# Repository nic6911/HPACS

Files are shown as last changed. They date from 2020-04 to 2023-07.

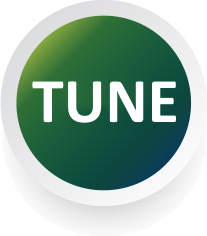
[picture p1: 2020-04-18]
Software/HMI/tune2.png

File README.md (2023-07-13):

# HPACS
Hot Plate Automatic Control System
Videos: https://youtu.be/TlVIJFjHHOQ and https://youtu.be/JZ1UPQ5lsyg

For a bit more details look here: https://www.instructables.com/Hot-Plate-Automatic-Control-System-HPACS/

If you like then please

"Buy Me A Coffee" (https://bmc.link/nic6911w)

## Purpose
This project aims at providing a simple intuitive way of understanding how to do Automatic PID tuning using a heater. What I have made is based on the Åström–Hägglund method for deriving parameters using bang-bang control to reveal system characteristics and subsequenctly chose parameters based on this knowledge. There is nothing secret to it and info can be found here: https://en.wikipedia.org/wiki/PID_controller#Loop_tuning
And for chosing parameters you can read a bit here: https://en.wikipedia.org/wiki/Ziegler%E2%80%93Nichols_method

To make it nice a Nextion 3.2" HMI interface is added for user input and displaying different variables real-time. BUT I also made a Serial terminal version of the library which makes the project way cheaper !

The real background story is that partly I promised my dad to make a temperature control for melting bees wax, partly I wanted to refresh my basic control theory and finally I wanted to look into auto tuning of PID controllers. On the side I also managed to use it for Sous Vide making nice steaks and Bearnaise sauce as part of the testing !

## Arduino based
The code is implemented on an Arduino Mega and uses two of the 16-bit timers for "PWM" and control loop. Furthermore, a Nextion 3.2" basic HMI panel is used on the HMI version of the code. I am not a software engineer so my coding may not be optimal or directly intuitive to others...

### Dependencies
I use a couple of libraries in the code: "DallasTemperature", "EEPROMex", "ITEADLIB_Arduino_Nextion-master" and the more commonly known "OneWire".

## Hardware/BOM
I use:
* A cheap WASCO Hot Plate 
* A cheap SS-relay
* A Dallas onewire temperature sensor 
* An Arduino Mega 
* (Optional) A Nextion 3.2" HMI interface/display

This work is licensed under a
[Creative Commons Attribution-ShareAlike 4.0 International License][cc-by-sa].

[][cc-by-sa]

[cc-by-sa]: http://creativecommons.org/licenses/by-sa/4.0/
[cc-by-sa-image]: https://licensebuttons.net/l/by-sa/4.0/88x31.png
[cc-by-sa-shield]: https://img.shields.io/badge/License-CC%20BY--SA%204.0-lightgrey.svg

Find more of my work here:  
https://youtube.com/user/wan46696  
https://www.instructables.com/member/nicengineering/  
        
License note: However, I have found the buttons for the HMI here: https://www.uihere.com/free-graphics/off-and-on-button-set-ai-eps-file-131170
Where it says "For Personal Use" under licensing - I.e. no commercialization of HPACS unless you change those buttons ;)
Also the disk icon and the hot surface warning I found somewhere at some point - but I can't seem to find them again...

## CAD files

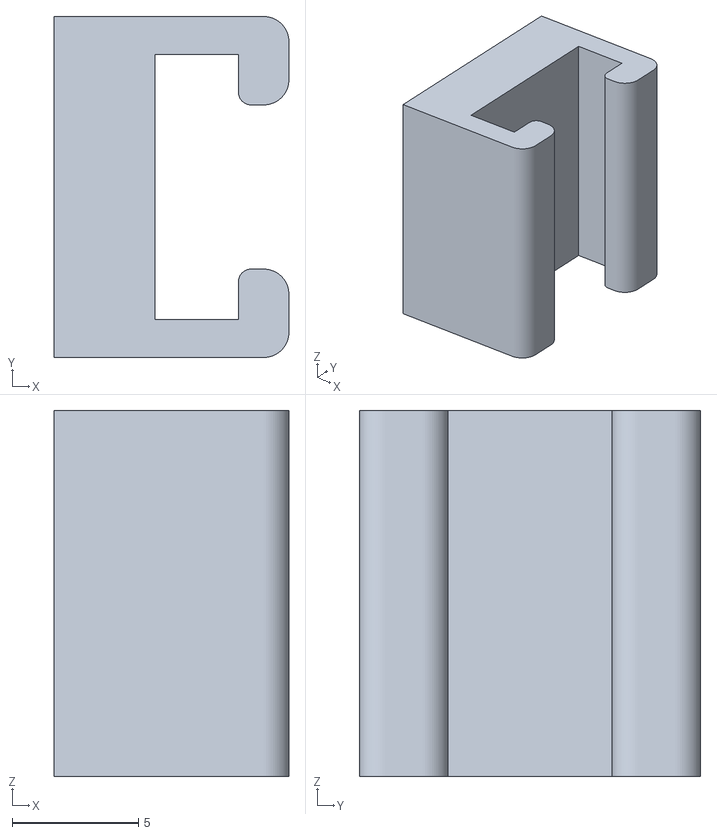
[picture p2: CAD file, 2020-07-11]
3Dfiles/Clamp_part2.stl
9.30 x 13.5 x 14.5

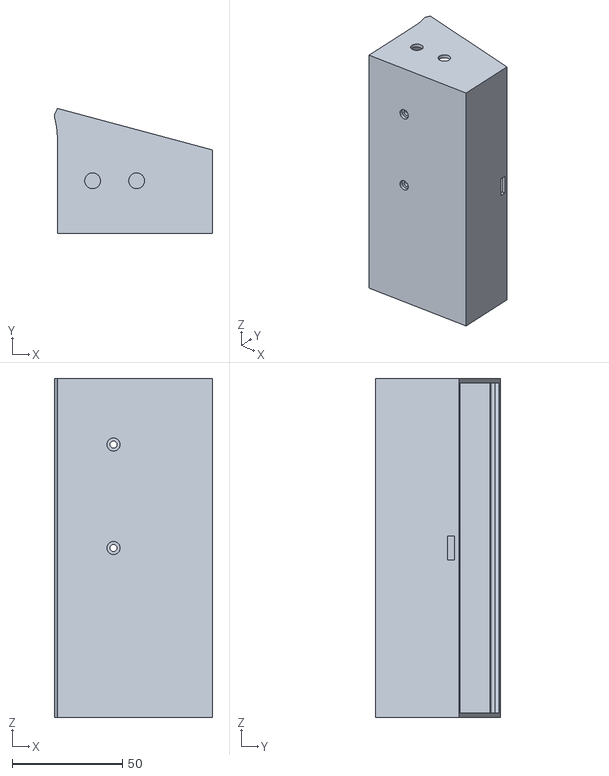
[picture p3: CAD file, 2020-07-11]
3Dfiles/Case.stl
71.8 x 56.9 x 154.0

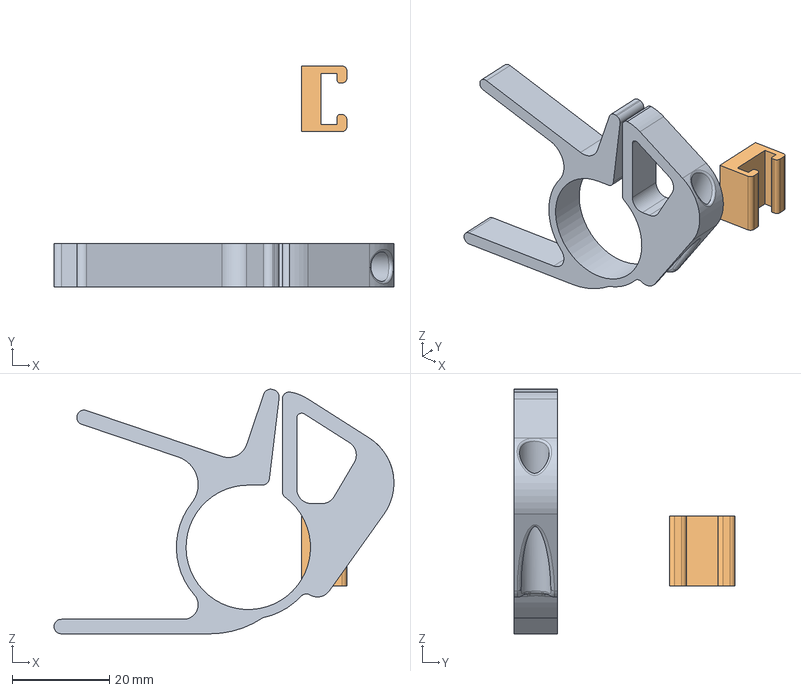
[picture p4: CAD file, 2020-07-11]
3Dfiles/clamp_temp.step
70.0 x 45.5 x 50.4 mm

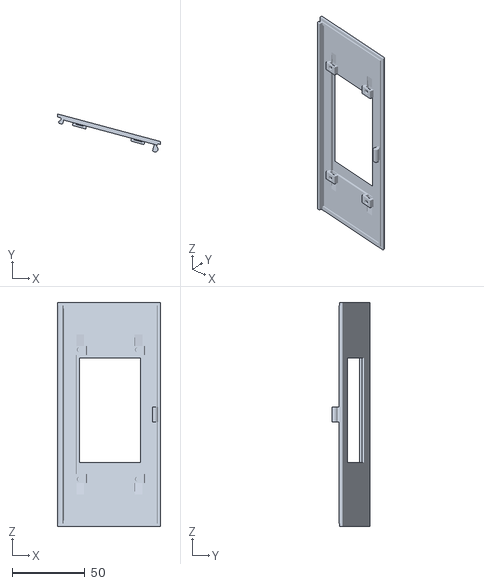
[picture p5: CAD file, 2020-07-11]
3Dfiles/Lid.stl
70.5 x 26.2 x 154.0

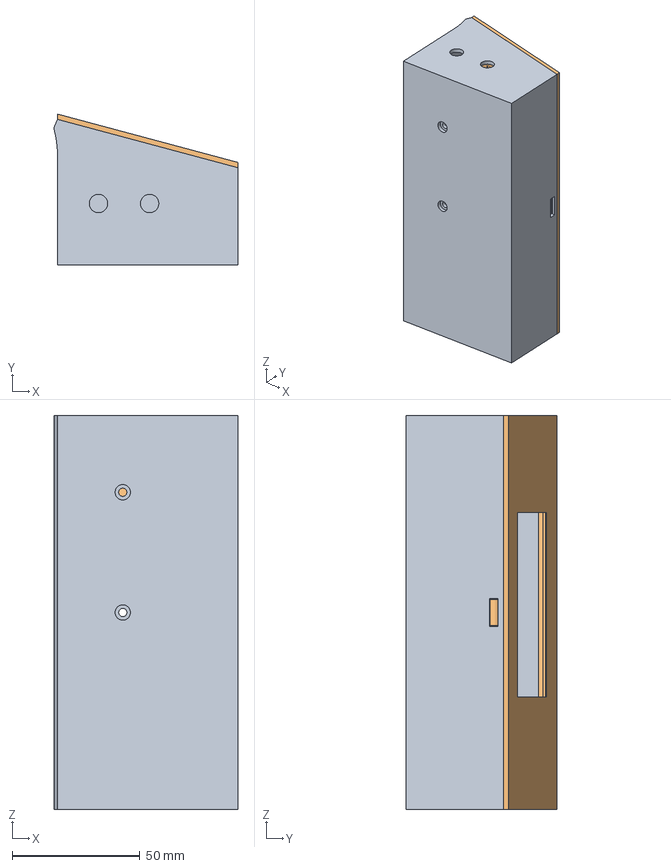
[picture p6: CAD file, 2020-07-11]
3Dfiles/Case_HMI.step
71.8 x 59.0 x 154.0 mm

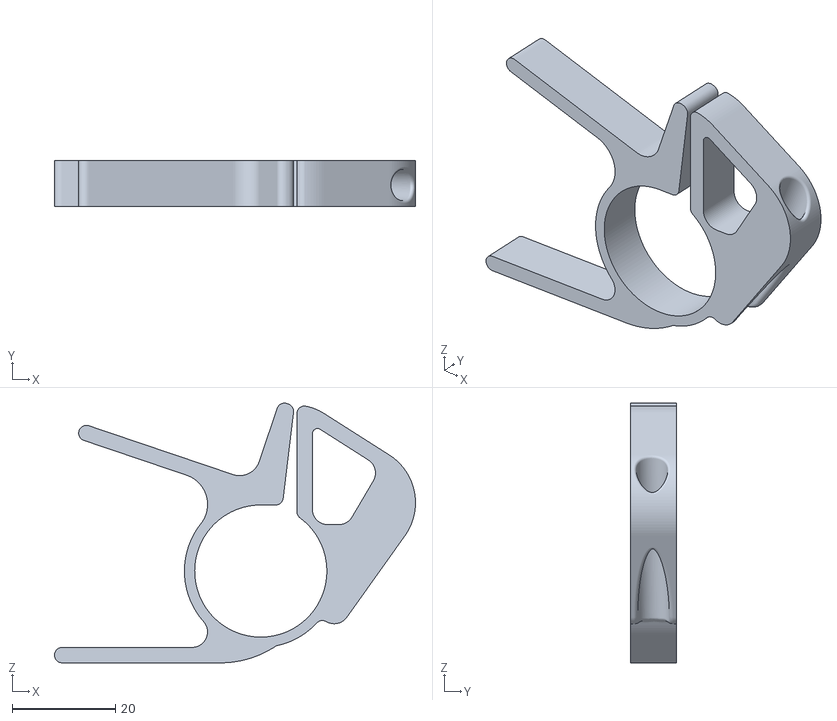
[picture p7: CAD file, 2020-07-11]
3Dfiles/Clamp.stl
70.0 x 9.00 x 50.4

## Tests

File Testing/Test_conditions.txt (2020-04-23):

Room temperature: ~25 degree
Water volume before disturbance: ~4 liter
Added water volume at disturbance: ~0.4 liter
Added water temperature: ~12 degrees
Fluid container: Pot with lid (not fully closed)

Gains calculated on automatic tuning with resulting parameters:
Tu: 1796
Ku: 23.282

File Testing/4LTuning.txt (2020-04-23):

48.00
48.06
48.13
48.13
48.13
48.19
48.19
48.25
48.25
48.25
48.25
48.31
48.31
48.38
48.44
48.50
48.50
48.56
48.63
48.63
48.69
48.75
48.75
48.81
48.81
48.81
48.88
48.88
48.88
48.94
48.94
48.94
49.00
49.00
49.00
49.06
49.06
49.13
49.13
49.13
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

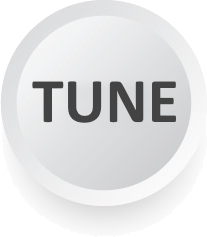
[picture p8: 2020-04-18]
Software/HMI/tune1.png

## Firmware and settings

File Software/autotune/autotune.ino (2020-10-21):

#include <OneWire.h>
#include <DallasTemperature.h>
#include <Nextion.h>//Remember to go into config.h for the library and change Serial1 to Serial1 !
#include <EEPROMex.h>

// Defines
#define ONE_WIRE_BUS 2
#define OFF 0
#define ON 1
#define AUTOTUNE 2
#define ABOVE 1
#define BELOW 0

//********* CONTROL SELECTION ****************//
// ONLY SELECT ONE !!!
//#define PCONTROL
//#define PICONTROL
//#define PDCONTROL
//#define CLASSICPID
#define PESSENCONTROL
//#define SOMEOVERSHOOT
//#define NOOVERSHOOT

// Setup a oneWire instance to communicate with any OneWire devices (not just Maxim/Dallas temperature ICs)
OneWire oneWire(ONE_WIRE_BUS);

// Pass our oneWire reference to Dallas Temperature. 
DallasTemperature sensors(&oneWire);

//********* GLOBAL VARIABLES ****************//
float setPoint = 55;
float Tmeas=0;
float error=0;
float Ki = 0.002;
float Kp = 1.1860;
float Kd = 467.2840;
uint8_t ontime = 0;
uint8_t stateMachine = OFF;
bool initTuning = 0;
uint8_t tempLimit = 100;// We do not allow more than 100 degree temperatures
// Controller variables
float integralOld;
float errorOld;
float yOld;
uint8_t cnt = 0;
uint8_t Tsample = 5;// sampletime = Tsample x 1 second

//********* SETUP OF NEXTION EVENTS ****************//
NexButton b0 = NexButton(0,3,"b0");//AUTOTUNE
NexButton b4 = NexButton(0,23,"b4");//ON
NexButton b1 = NexButton(0,24,"b1");//OFF
NexButton b5 = NexButton(0,25,"b5");//SAVE
NexNumber x2=NexNumber(0,6,"x2");
NexNumber x3=NexNumber(0,7,"x3");
NexNumber x4=NexNumber(0,31,"x4");
NexNumber x0=NexNumber(0,2,"x0");

NexTouch *nex_listen_list[] = 
{
  &b1,
  &b4,
  &b0,
  &b5,
  &x2,
  &x3,
  &x4,
  &x0,
  NULL
};

void b5PushCallback(void *ptr)
{
  b5.detachPush();  // Button press detached to avoid multiple presses to save
  uint32_t setPointMem = 0;
  uint32_t KpMem = 0;
  uint32_t KiMem = 0;
  uint32_t KdMem = 0;
  x2.getValue(&KpMem);
  Kp = (float)(KpMem*0.001);
  x3.getValue(&KiMem);
  Ki = (float)(KiMem*0.001);
  x4.getValue(&KdMem);
  Kd = (float)(KdMem*0.1);
  x0.getValue(&setPointMem);
  setPoint = (float)(setPointMem*0.1);
  EEPROM.writeLong(0,KpMem);
  EEPROM.writeLong(4,KiMem);
  EEPROM.writeLong(8,KdMem);
  EEPROM.writeLong(12,setPointMem);
  Serial1.print("b5.pic=");Serial1.print(10);Serial1.write(0xff);Serial1.write(0xff);Serial1.write(0xff);
}
void b4PushCallback(void *ptr)
{
  uint32_t number2 = 0;
  stateMachine = ON;
  x0.getValue(&number2);
  setPoint = (float)(number2*0.1);
}

void b1PushCallback(void *ptr)
{
  stateMachine = OFF;
}

void b0PushCallback(void *ptr)
{
  uint32_t number2 = 0;
  stateMachine = AUTOTUNE;
  x0.getValue(&number2);
  setPoint = (float)(number2*0.1);
}

void x2PushCallback(void *ptr)
{
  b5.attachPush(b5PushCallback);// If someone may have eited a PID parameter we enable the save button again
}

void x3PushCallback(void *ptr)
{
  b5.attachPush(b5PushCallback);// If someone may have eited a PID parameter we enable the save button again
}

void x4PushCallback(void *ptr)
{
  b5.attachPush(b5PushCallback);// If someone may have eited a PID parameter we enable the save button again
}

void setup(){
  Serial.begin(9600);
  // Load PID and setpoint from EEPROM
  uint32_t KpMem = EEPROM.readLong(0);
  uint32_t KiMem = EEPROM.readLong(4);
  uint32_t KdMem = EEPROM.readLong(8);
  uint32_t setPointMem = EEPROM.readLong(12);
  if(KpMem>32000)//limit size for the HMI not to fuck up
  {
    KpMem=32000;
  }
  if(KiMem>32000)//limit size for the HMI not to fuck up
  {
    KiMem=32000;
  }
  if(KdMem>32000)//limit size for the HMI not to fuck up
  {
    KdMem=32000;
  }
  if(setPointMem>1000)
  {
    setPointMem=1000;
  }  
  Kp = (float)KpMem*0.001;
  Ki = (float)KiMem*0.001;
  Kd = (float)KdMem*0.1;
  setPoint = (float)setPointMem*0.1;
  Serial1.begin(9600);
  sensors.begin();
  delay(1000);
  sensors.requestTemperatures(); // Send the command to get temperatures
  sensors.getTempCByIndex(0);
  //Send loaded values to display
  Serial1.print("x2.val=");Serial1.print(KpMem);Serial1.write(0xff);Serial1.write(0xff);Serial1.write(0xff);
  Serial1.print("x3.val=");Serial1.print(KiMem);Serial1.write(0xff);Serial1.write(0xff);Serial1.write(0xff);
  Serial1.print("x4.val=");Serial1.print(KdMem);Serial1.write(0xff);Serial1.write(0xff);Serial1.write(0xff);
  Serial1.print("x0.val=");Serial1.print(setPointMem);Serial1.write(0xff);Serial1.write(0xff);Serial1.write(0xff);
  Serial1.print("va1.val=");Serial1.print(0);Serial1.write(0xff);Serial1.write(0xff);Serial1.write(0xff);
  Serial1.print("va2.val=");Serial1.print(0);Serial1.write(0xff);Serial1.write(0xff);Serial1.write(0xff);
  Serial1.print("va3.val=");Serial1.print(0);Serial1.write(0xff);Serial1.write(0xff);Serial1.write(0xff);
  // Attach pushbuttons from nextion
  b4.attachPush(b4PushCallback);  // Button press
  b1.attachPush(b1PushCallback);  // Button press
  b0.attachPush(b0PushCallback);  // Button press
  b5.attachPush(b5PushCallback);  // Button press
  x2.attachPush(x2PushCallback);
  x3.attachPush(x3PushCallback);
  x4.attachPush(x4PushCallback);
  
  //Setup the PWM for the SS relay
cli();//stop interrupts
  DDRH |= (1 << DDH3);//D6 on arduino mega for PWM
  //set timer4 for PWM at 0.238Hz = 4.2seconds
  TCCR4A = 0;// set entire TCCR1A register to 0
  TCCR4B = 0;// same for TCCR1B
  TCNT4  = 0;//initialize counter value to 0
  // set TOP to 16bit
  ICR4 = 0xFFFF;
  //Dutycycle of the PWM
  OCR4A = 0x0000;//0xEFFF;//25% duty
  // set none-inverting mode
  TCCR4A |= (1 << COM4A1);
  // set Fast PWM mode using ICR1 as TOP
  TCCR4A |= (1 << WGM41);
  TCCR4B |= (1 << WGM42)|(1 << WGM43);
  // Set CS12 and CS10 bits for 1024 prescaler
  TCCR4B |= (1 << CS42) | (1 << CS40);  

// Set timer5 interrupt at 1Hz to run the control
 TCCR5A = 0;// set entire TCCR1A register to 0
 TCCR5B = 0;// same for TCCR1B
 TCNT5  = 0;//initialize counter value to 0
 // set compare match register for 1hz increments
 OCR5A = 15625/1;// = (16*10^6) / (1*1024) - 1 (must be <65536) -> 15625
 // turn on CTC mode
 TCCR5B |= (1 << WGM52);
 // Set CS12 and CS10 bits for 1024 prescaler
 TCCR5B |= (1 << CS52) | (1 << CS50);  
 // enable timer compare interrupt
 TIMSK5 |= (1 << OCIE5A);  
sei();//allow interrupts
}//end setup

ISR(TIMER5_COMPA_vect){//timer5 interrupt 1Hz 
 sensors.requestTemperatures(); // Send the command to get temperatures
 Tmeas = sensors.getTempCByIndex(0);// Get temperature
 error = (setPoint-Tmeas);// Calculate error
 // State machine here
 if(stateMachine == ON)
 {
  if(cnt>(Tsample-1))
  {
  ontime = Controller(error);
  cnt=0;
  }
  cnt++;
  initTuning = 1;
 }
 else if(stateMachine == OFF)
 {
  ontime = 0;
  initTuning = 1;
  // Reset controller
  integralOld = 0;
  errorOld = 0;
  yOld = 0;
 }
 else if(stateMachine == AUTOTUNE)
 {
  tuning();
 }

 // Send temperature to display
 Serial1.print("x1.val=");Serial1.print((uint16_t)(Tmeas*10));Serial1.write(0xff);Serial1.write(0xff);Serial1.write(0xff);

 if(Tmeas>tempLimit)// We do not allow more than the tempLimit !
 {
  ontime = 0;
 }

 // Update PWM register
 OCR4A = map(ontime,0,100,0x0,0xFFFF);//Set PWM duty cycle
}

//********* CONTROLLER ****************//
uint8_t Controller(float error)
{
  float limit = 100.0;
  float y;
  float integral;
  static float der = 0;
  float alpha = 0.4;//Alpha = 1 equals no filtering whereas alpha = 0.1 is a lot of low-pass filtering...
  
  der = der + alpha*((error-errorOld) - der);
  
  errorOld = error;

  // Anti wind-up using clamping of the integrator
  if((yOld>limit && error > 0)|| (yOld<0 && error < 0))
  {
    integral = integralOld;
  }
  else
  {
    integral = integralOld + (error*Tsample)*Ki;
  }
  if(integral > limit)//this may actually be needed if we have a very slow process. The D can give a negative term that allows the integrator to build up and exceed the limit theoretically...
  {
    integral = integralOld;
  }

  y = (integral + Kp*error + Kd*der);// 
  
  yOld = y;
  if(y<0)
  {
    y=0;
  }
  if(y>limit)
  {
    y=limit;
  }
  
  integralOld = integral;
  return (uint8_t)y;
}

//********* AUTOTUNE ****************//
void tuning()
{
  uint8_t cycles = 3;// How many proper cycles we want - can be put as an editable global
  float duty = 40;// How much dutycycle we want to do the tuning with - can be but as an editable global
  uint16_t timeVariation = 90;//Allowable cycle time variation in seconds - can be but as an editable global
  float tempVariation = 2.0;// Allowable variation of temprature between cycles  - can be but as an editable global
  uint32_t time1 = 0;// For calculating cycle time
  float Tu;// Ultimate period
  float Ku;// Ultimate gain
  // Variables below are required to be static
  static float deltaT[11];
  static uint32_t deltaTime[11];
  static uint8_t count = 0;
  static bool state = BELOW;
  static float Tmax = 0;// For recording the max temperature of a cycle
  static float Tmin = 255;// For recording the min temperature of a cycle
  static uint32_t time2 = 0;// For calculating cycle time
  static uint8_t k = 0;
  static bool tuneOver = 0;
  static bool bufFull = 0;
  static float avgDeltaT = 0;
  static uint8_t check = 0;
  static bool flag = 0;
  static float avgDeltaTime = 0;

  if(initTuning > 0)//reinitialize tuning parameters
  {
    count = 0;
    state = BELOW;
    Tmax = 0;
    Tmin = 255;
    time2 = 0;
    k = 0;
    tuneOver = 0;
    bufFull = 0;
    avgDeltaT = 0;
    check = 0;
    flag = 0;
    avgDeltaTime = 0;
    initTuning = 0;
    if(error>0)
    {
      state = ABOVE;
    }
  }

  // Limit the number of allowable cycles
  if(cycles > 10)
  {
    cycles = 10;
  }
  else if(cycles < 3)
  {
    cycles = 3;
  }
  
  if(bufFull<1)// If we do not have a full buffer (i.e. less than defined cycles have completed)
  {
    if(error<0 && state == BELOW)
    {
      count++;
      if(count>10)
      {
        if(k>=cycles)
        {
          k = 0;
          bufFull = 1;
          flag = 1;// This is to see that we have looped over the FIFO once and thus do not need to start all over
        }
        ontime = 0;
        count = 0;
        state = ABOVE;
        time1 = millis()*0.001;
        if(time2>0)//ignore the first time since we do not have a valid time2
        {
          deltaTime[k] = time1-time2;
          deltaT[k] = Tmax-Tmin;
          k++;
        }
        Tmin = 255;
        Tmax = 0;
        time2 = time1;
        if(flag == 1)// Since we have been at FIFO end once the buffer is still considered full
        {
          bufFull=1;
        }
      }
    }
    
    if(state == ABOVE && error < 0)
    {
      if(Tmeas>Tmax)
      {
        Tmax = Tmeas;
      }
      if(error < -0.2*setPoint)
      {
        ontime = 0;
      }
    }
  
    if(state ==  ABOVE && error>0)
    {
        count++;
        if(count>10)
        {
          ontime = duty;
          count = 0;
          state = BELOW;  
        }
    }
    
    if(state == BELOW && error>0)
    {
      if(Tmeas<Tmin)
      {
        Tmin = Tmeas;
      }
      if(error>0.2*setPoint)
      {
        ontime = duty;
      }
    }
  }
  else
  {
    for(int i=1;i<cycles;i++)
    {
      int32_t periodVar = deltaTime[0]-deltaTime[i];
      float tempVar = deltaT[0]-deltaT[i];
      if(abs(periodVar)<timeVariation)
      {
        check++;
      }
      if(abs(tempVar)<tempVariation)
      {
        check++;
      }
    }
    if(check == 2*(cycles-1))
      {
        tuneOver = 1;
        avgDeltaT = 0;
        check=0;
      }
      else
      {
        bufFull = 0;
        state = ABOVE;
        check=0;
      }
  }
  
  if(tuneOver >0)
  {
    ontime = 0;
    for(int i=0;i<cycles;i++)
    {
      avgDeltaT += deltaT[i]/cycles;
      avgDeltaTime += deltaTime[i]/cycles;
    }
    // Calculate ultimate period and gain
    Tu = avgDeltaTime;
    Ku = (4*duty)/(PI*avgDeltaT);
    #ifdef PCONTROL
    // P-control
    Kp = 0.5*Ku;
    Ki = 0;
    Kd = 0;
    #endif
    #ifdef PICONTROL
    // PI-control
    Kp = 0.45*Ku;//4.66
    Ki = 0.54*Ku/Tu;//0.004
    Kd = 0;
    #endif
    #ifdef PDCONTROL
    // PD-control
    Kp = 0.8*Ku;
    Ki = 0;
    Kd = Ku*Tu*0.1;
    #endif
    #ifdef CLASSICPID
    Kp = 0.6*Ku;
    Ki = 1.2*Ku/Tu;
    Kd = Ku*Tu*0.075;
    #endif
    #ifdef PESSENCONTROL
    Kp = 0.7*Ku;
    Ki = 1.75*Ku/Tu;
    Kd = Ku*Tu*0.105;
    #endif
    #ifdef SOMEOVERSHOOT
    Kp = 0.333*Ku;
    Ki = 0.666*Ku/Tu;
    Kd = Ku*Tu*0.111;
    #endif
    #ifdef NOOVERSHOOT
    // Ziegler Nichols no overshoot PID parameters with lowered Kd
    Kp = Ku*0.2;//10.355Ku
    Ki = (0.4*Ku)/Tu;//1380Tu
    Kd = Ku*Tu*0.06;
    #endif
    Ki = Ki;
    Kd = Kd/Tsample;
    stateMachine = OFF;
    if(Kp>32)//limit size for the HMI not to fuck up
    {
      Kp=32;
    }
    if(Ki>32)//limit size for the HMI not to fuck up
    {
      Ki=32;
    }
    if(Kd>3200)//limit size for the HMI not to fuck up
    {
      Kd=3200;
    }
    Serial1.print("x2.val=");Serial1.print((uint32_t)(Kp*1000));Serial1.write(0xff);Serial1.write(0xff);Serial1.write(0xff);
    Serial1.print("x3.val=");Serial1.print((uint32_t)(Ki*1000));Serial1.write(0xff);Serial1.write(0xff);Serial1.write(0xff);
    Serial1.print("x4.val=");Serial1.print((uint32_t)(Kd*10));Serial1.write(0xff);Serial1.write(0xff);Serial1.write(0xff);
    Serial1.print("b5.pic=");Serial1.print(7);Serial1.write(0xff);Serial1.write(0xff);Serial1.write(0xff);// Save icon is gray
    Serial1.print("va1.val=");Serial1.print(0);Serial1.write(0xff);Serial1.write(0xff);Serial1.write(0xff);
    Serial1.print("va2.val=");Serial1.print(0);Serial1.write(0xff);Serial1.write(0xff);Serial1.write(0xff);
    Serial1.print("va3.val=");Serial1.print(0);Serial1.write(0xff);Serial1.write(0xff);Serial1.write(0xff);
    b5.attachPush(b5PushCallback);  // Button press enabled to be able to save parameters
  }
}

void loop(){
  nexLoop(nex_listen_list);  // Check for any touch event
}

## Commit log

2020-04-18 Edited the EEPROM and fixed bug
    A bug around reading/writing to the display with regards to scaling was fixed. EEPROM read/write was updated...
    [autotune.ino]
2020-04-18 Fixed EEPROM
    EEPROM still had flaws - now it should be okay !
    [autotune.ino]
2020-04-19 edited HMI and controller
    removed a digit for the Kd and corrected windup + Kd term
    [autotune.ino]
2020-06-05 corrected fault with HMI
    overflow on values transferred to HMI
    [autotune.ino]
2020-07-11 Added 3D files
    [Case.stl, Case_HMI.step, Clamp.stl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]
2020-10-21 Error in integrator fixed
    [autotune.ino, autotune_serial_menu.ino]

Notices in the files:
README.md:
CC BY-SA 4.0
